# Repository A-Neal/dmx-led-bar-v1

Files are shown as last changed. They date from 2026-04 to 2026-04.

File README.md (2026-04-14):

# FPGA DMX Decoder and PWM Driver Written in Verilog

This project directory is uploaded as-is, and doesn't contain a lot of polish.

I used Apio to build the Verilog into a configuration for the FPGA, and developed
on a Lattice iCE40UP5k. You can use the underlying toolchain if you'd prefer, but
I recommend Apio if you aren't looking to get into the weeds and just want to
modify little bits of the Verilog or build it for a different FPGA.

If you are building exactly according to what's in this repo, you don't need to
have Apio or build the configuration. **hardware.bin** is the file that is already
built and padded to fit into the 2Mbit flash on the PCB.

To flash, I used a generic CH341A USB SPI flasher with `flashrom` to flash the
hardware.bin file.

`$ flashrom -p ch341a_spi -w hardware.bin`

This repo includes the KiCAD project for the PCB, as well as just the gerber files
for have the PCB produced if you don't want to do any mods.

The BOM file is a list of everything that goes on the PCB and a link to the part
on Mouser. It's inside the KiCAD project directory.

The LED strips I used get a little too hot for the channels I used when everything
is turned up, so I'm not going to recommend them. But I will link them anyway
because they're excellent for other uses or if you're building a beefier fixture
than these plans are for.

LED Strip I Used: https://a.co/d/0fOELpNe

Less Powerful Equivalent LED Strip: https://a.co/d/0jd0L9jr

Aluminum Diffuser Channels: https://a.co/d/0e7rKbcg

24V Power Supply: https://a.co/d/09dPfuRe

Use any 12-24V LED strip and power supply that you want so long as the strip fits
in the channels, and the power supply can push enough power comfortably.

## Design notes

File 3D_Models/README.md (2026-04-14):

# 3D Files

The 3mf files are ready for loading into your favorite slicer for 3D printing, and the FreeCAD project files are available for modifying directly. Most things in the project files are parameterized.

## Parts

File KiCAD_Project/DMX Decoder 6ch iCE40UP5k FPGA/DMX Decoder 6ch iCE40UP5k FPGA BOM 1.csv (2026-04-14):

Reference | Qty | Value | Notes | Footprint | Manufacturer | MFR Part # | Mouser Part #
C1,C12,C13,C14 | 4 | 10μF |  | Capacitor_SMD:C_0603_1608Metric | Samsung Electro-Mechanics | CL10A106KP8NQSC | 187-CL10A106KP8NQSC
C2,C3,C4,C5,C6,C7,C8,C9,C10,C11,C15,C16 | 12 | 100nF |  | Capacitor_SMD:C_0603_1608Metric | TAIYO YUDEN | UMK107BJ104KA-T | 963-UMK107BJ104KA-T
D1 | 1 | CDONE LED |  | LED_SMD:LED_0805_2012Metric | ROHM Semiconductor | SMLMN2BCTT86C | 755-SMLMN2BCTT86C
D2 | 1 | 10V Zener |  | Diode_SMD:D_SOD-123 | Vishay Semiconductor | BZT52C10-E3-18 | 78-BZT52C10-E3-18
J3 | 1 | IN - MALE |  | Connector_Audio:Jack_XLR_Neutrik_NC5MAV_Vertical | Neutrik/REAN | RRX5M-B-023-0 | 568-RRX5M-B-023-0
J4 | 1 | OUT - FEMALE |  | Connector_Audio:Jack_XLR_Neutrik_NC5FAV_Vertical | Neutrik/REAN | RRX5F-B-022-0 | 568-RRX5F-B-022-0
Q1,Q2,Q3,Q4,Q5,Q6 | 6 | T2N7002AK N-MOSFET |  | Package_TO_SOT_SMD:SOT-23 | Toshiba | T2N7002AK,LM | 757-T2N7002AKLM
Q7,Q8,Q9,Q10,Q11,Q12 | 6 | DMG4496SSS N-MOSFET |  | Package_SO:SOIC-8_3.9x4.9mm_P1.27mm | Diodes Incorporated | DMG4496SSS13 | 621-DMG4496SSS13
Q14 | 1 | SI4435 P-MOSFET |  | Package_TO_SOT_SMD:SOT-23 | Vishay / Siliconix | SI4435FDY-T1-GE3 | 78-SI4435FDY-T1-GE3
R1,R2,R3,R4,R5,R6 | 6 | 5.1k |  | Resistor_SMD:R_0603_1608Metric | Panasonic | ERJ-U03F5101V | 667-ERJ-U03F5101V
R7,R8,R9,R10,R11,R12 | 6 | 3.3k |  | Resistor_SMD:R_0603_1608Metric | Panasonic | ERJ-U03F3301V | 667-ERJ-U03F3301V
R13 | 1 | 100Ω |  | Resistor_SMD:R_0603_1608Metric | Panasonic | ERJ-U03F1000V | 667-ERJ-U03F1000V
R14,R16,R17,R18,R19,R20 | 6 | 10k |  | Resistor_SMD:R_0603_1608Metric | Panasonic | ERJ-U03F1002V | 667-ERJ-U03F1002V
R15 | 1 | 2.2k |  | Resistor_SMD:R_0603_1608Metric | Panasonic | ERJ-U03F2201V | 667-ERJ-U03F2201V
U1 | 1 | ICE40UP5K-SG48ITR |  | Package_DFN_QFN:QFN-48-1EP_7x7mm_P0.5mm_EP5.6x5.6mm | Lattice | ICE40UP5K-SG48I | 842-ICE40UP5K-SG48I
U2 | 1 | THVD1420D |  | Package_SO:SOIC-8_3.9x4.9mm_P1.27mm | Texas Instruments | THVD1420DR | 595-THVD1420DR
U3 | 1 | AT25xxx-MA |  | Package_DFN_QFN:DFN-8-1EP_3x2mm_P0.5mm_EP1.75x1.45mm | Renesas Electronics | AT25EU0021AMAHNT | 724-AT25EU0021AMAHNT
U4 | 1 | 1.2V REG |  | Package_SON:WSON-6-1EP_2x2mm_P0.65mm_EP1x1.6mm | Texas Instruments | TPS70912DRVT | 595-TPS70912DRVT
U5 | 1 | 2.5V REG |  | Package_SON:WSON-6-1EP_2x2mm_P0.65mm_EP1x1.6mm | Texas Instruments | TPS70925DRVR | 595-TPS70925DRVR
U6 | 1 | 3.3V REG |  | Package_SON:WSON-6-1EP_2x2mm_P0.65mm_EP1x1.6mm | Texas Instruments | TPS70933DRVR | 595-TPS70933DRVR
Y1 | 1 | ASCO 12MHz |  | Oscillator:Oscillator_SMD_Abracon_ASCO-4Pin_1.6x1.2mm | Microchip | DSC1001DI5-012.0000 | 998-DSC1001DI5-012.0000
J1 | 1 | LED STRIP CATHODES 1-6 | Generic Screw Terminals | TerminalBlock:TerminalBlock_MaiXu_MX126-5.0-06P_1x06_P5.00mm | GCT | TAH05-02-1-L-G | 640-TAH05-02-1-L-G
J2 | 1 | 24V Input Pos-C | Generic horizontal 5mm barrel jack | Custom:BarrelJack_Horizontal_CUI_PJ-057A | Same Sky (Formerly CUI) | PJ-057A | 490-PJ-057A
J5 | 1 | FLASH SPI | Generic 0.100” pitch pin headers | Connector_PinHeader_2.54mm:PinHeader_1x06_P2.54mm_Vertical | Amphenol | 77311-122-06LF | 649-77311-122-06LF
J6 | 1 | 24V COM | Generic Screw Terminals | TerminalBlock:TerminalBlock_MaiXu_MX126-5.0-02P_1x02_P5.00mm | GCT | TAH05-02-1-L-G | 640-TAH05-02-1-L-G
JP1 | 1 | RST JMPR | Generic 0.050” pitch pin headers | Connector_PinHeader_1.27mm:PinHeader_1x02_P1.27mm_Vertical | Samtec | TMS-102-21-G-S | 200-TMS-102-21-G-S

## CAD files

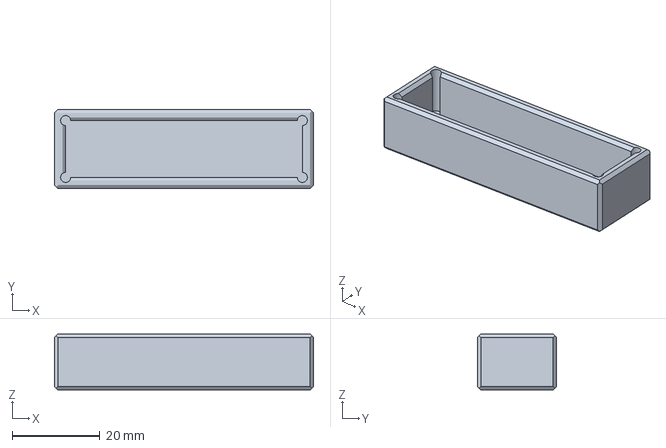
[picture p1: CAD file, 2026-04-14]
3D_Models/LED Bar End Cap 2.3mf
59.1 x 18.0 x 12.7 mm

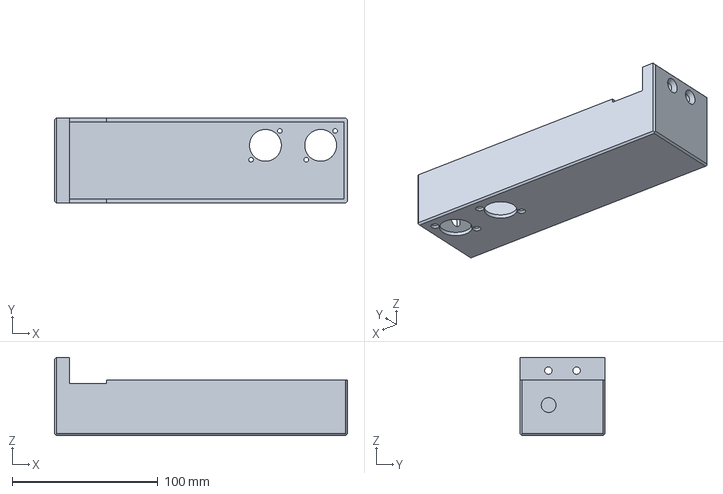
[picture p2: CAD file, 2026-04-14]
3D_Models/LED Bar PCB Box.3mf
201.2 x 58.2 x 53.6 mm

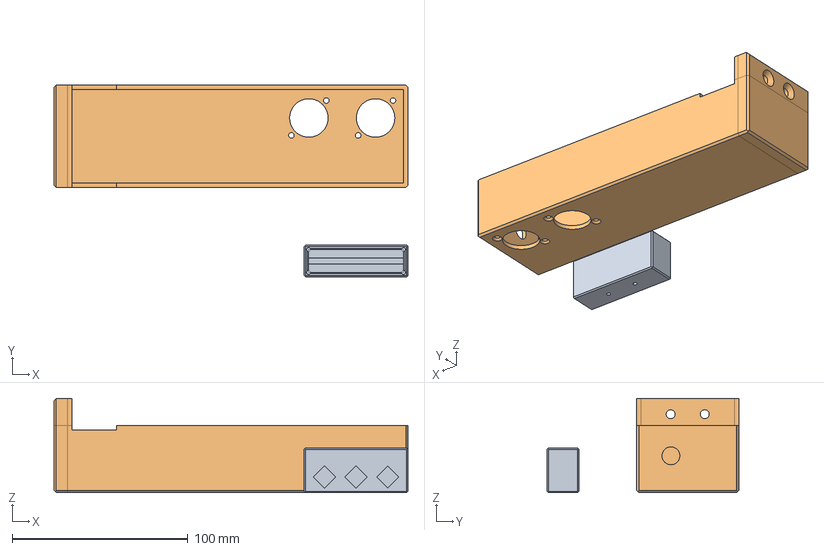
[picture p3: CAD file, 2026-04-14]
3D_Models/LED Bar DMX End Cap.FCStd
201.2 x 109.0 x 53.6 mm

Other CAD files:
3D_Models/LED Bar End Cap.FCStd
3D_Models/LED Bar DMX End Cap.3mf

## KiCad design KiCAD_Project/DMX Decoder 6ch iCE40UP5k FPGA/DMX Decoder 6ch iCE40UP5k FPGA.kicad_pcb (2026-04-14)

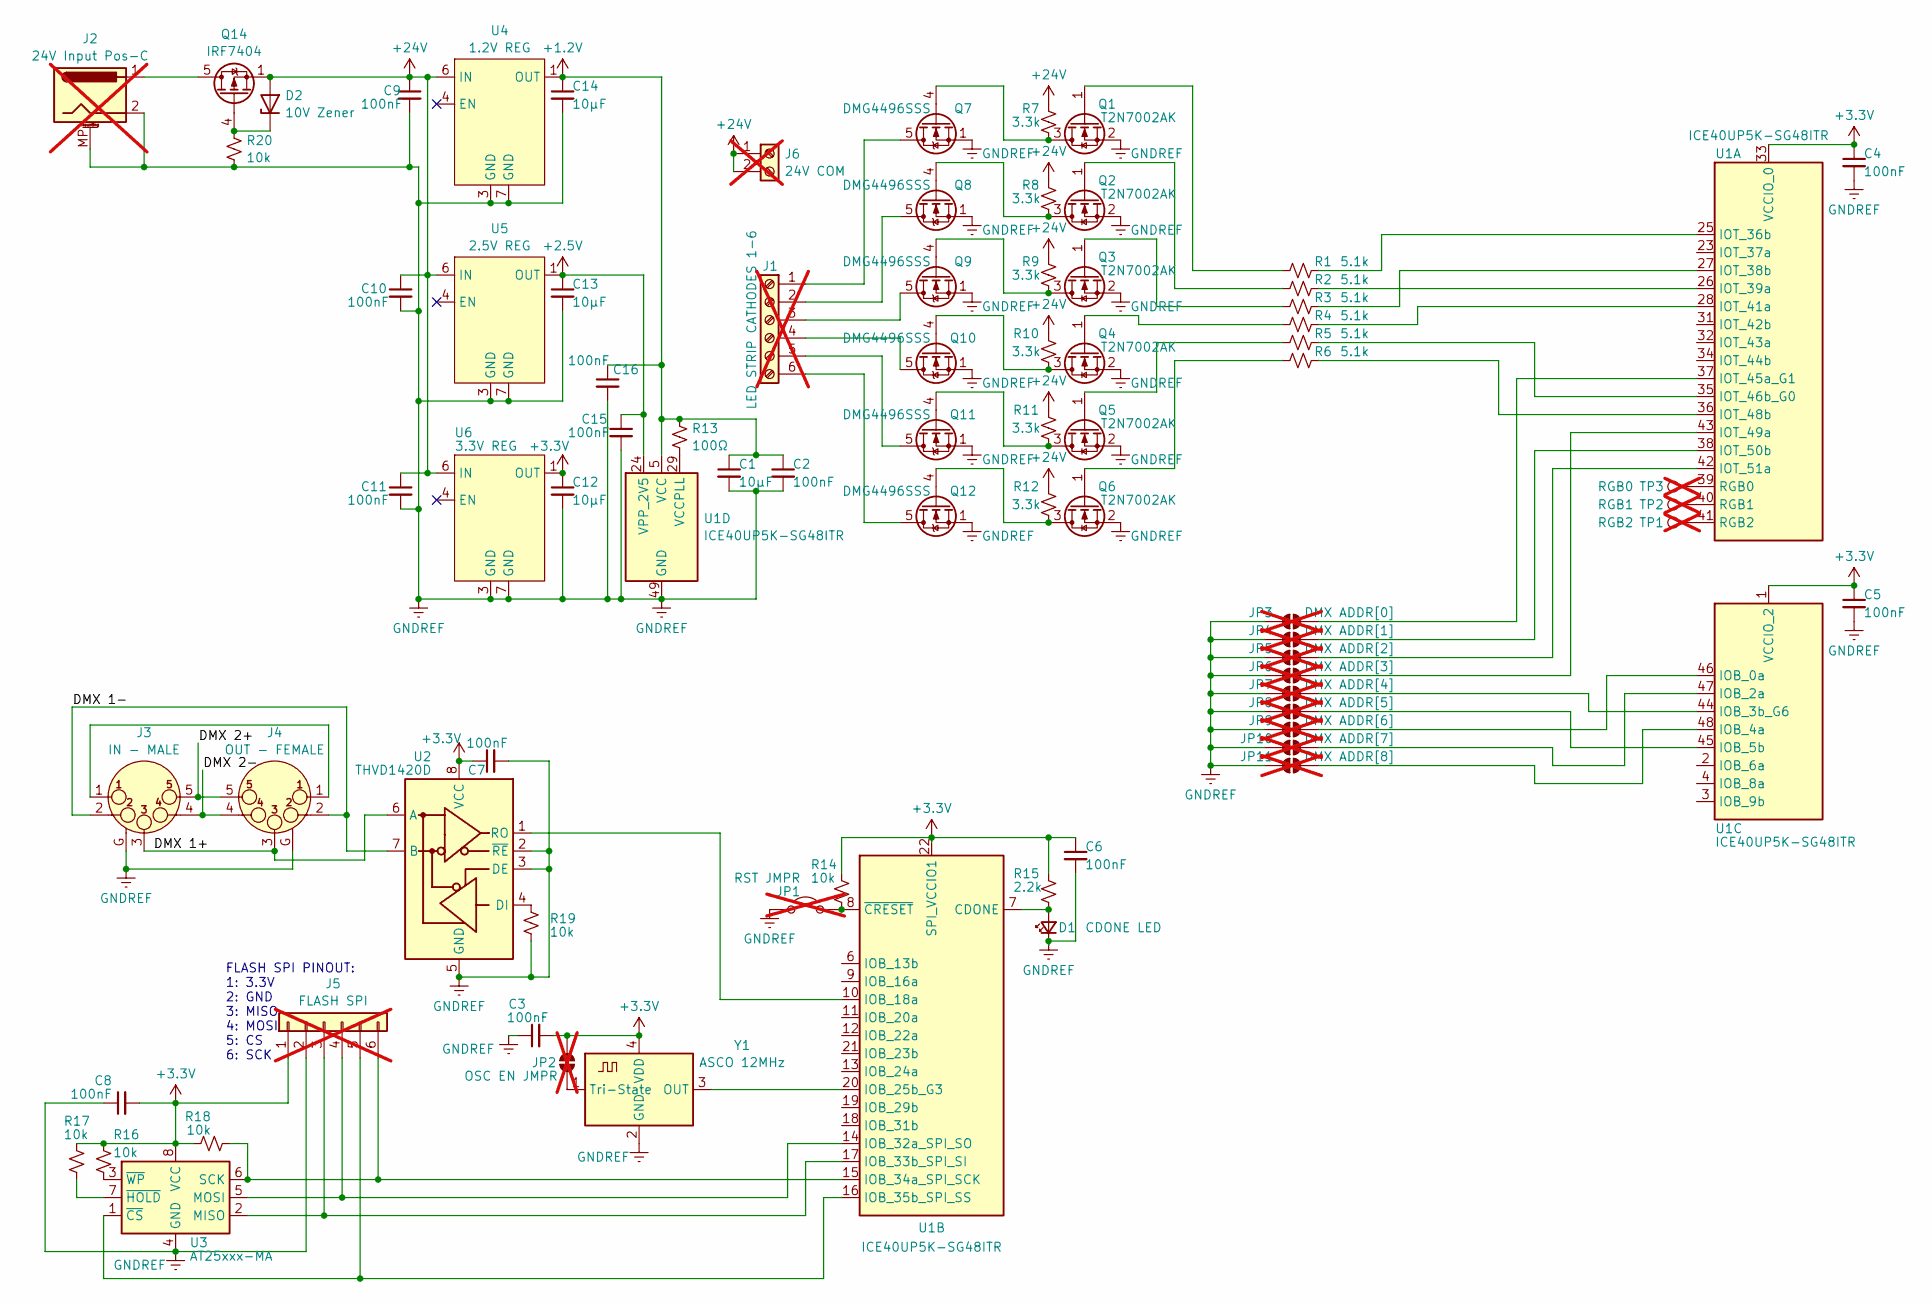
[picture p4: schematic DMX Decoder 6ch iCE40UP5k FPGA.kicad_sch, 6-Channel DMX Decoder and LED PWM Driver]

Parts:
C1, C12, C13, C14: 10μF; C_0603_1608Metric
C2, C3, C4, C5, C6, C7, C8, C9, C10, C11, C15, C16: 100nF; C_0603_1608Metric
D1: CDONE LED; LED_0805_2012Metric
D2: 10V Zener; D_SOD-123
J1: LED STRIP CATHODES 1-6; TerminalBlock_MaiXu_MX126-5.0-06P_1x06_P5.00mm; not fitted
J2: 24V Input Pos-C; BarrelJack_Horizontal_CUI_PJ-057A; not fitted
J3: IN - MALE; Jack_XLR_Neutrik_NC5MAV_Vertical
J4: OUT - FEMALE; Jack_XLR_Neutrik_NC5FAV_Vertical
J5: FLASH SPI; PinHeader_1x06_P2.54mm_Vertical; not fitted
J6: 24V COM; TerminalBlock_MaiXu_MX126-5.0-02P_1x02_P5.00mm; not fitted
JP1: RST JMPR; PinHeader_1x02_P1.27mm_Vertical; not fitted
JP2: OSC EN JMPR; SolderJumper-2_P1.3mm_Open_TrianglePad1.0x1.5mm; not fitted
JP3: DMX ADDR[0]; SolderJumper-2_P1.3mm_Open_TrianglePad1.0x1.5mm; not fitted
JP4: DMX ADDR[1]; SolderJumper-2_P1.3mm_Open_TrianglePad1.0x1.5mm; not fitted
JP5: DMX ADDR[2]; SolderJumper-2_P1.3mm_Open_TrianglePad1.0x1.5mm; not fitted
JP6: DMX ADDR[3]; SolderJumper-2_P1.3mm_Open_TrianglePad1.0x1.5mm; not fitted
JP7: DMX ADDR[4]; SolderJumper-2_P1.3mm_Open_TrianglePad1.0x1.5mm; not fitted
JP8: DMX ADDR[5]; SolderJumper-2_P1.3mm_Open_TrianglePad1.0x1.5mm; not fitted
JP9: DMX ADDR[6]; SolderJumper-2_P1.3mm_Open_TrianglePad1.0x1.5mm; not fitted
JP10: DMX ADDR[7]; SolderJumper-2_P1.3mm_Open_TrianglePad1.0x1.5mm; not fitted
JP11: DMX ADDR[8]; SolderJumper-2_P1.3mm_Open_TrianglePad1.0x1.5mm; not fitted
Q1, Q2, Q3, Q4, Q5, Q6: T2N7002AK; SOT-23
Q7, Q8, Q9, Q10, Q11, Q12: DMG4496SSS; SOIC-8_3.9x4.9mm_P1.27mm
Q14: IRF7404; SOIC-8_3.9x4.9mm_P1.27mm
R1, R2, R3, R4, R5, R6: 5.1k; R_0603_1608Metric
R7, R8, R9, R10, R11, R12: 3.3k; R_0603_1608Metric
R13: 100Ω; R_0603_1608Metric
R14, R16, R17, R18, R19, R20: 10k; R_0603_1608Metric
R15: 2.2k; R_0603_1608Metric
TP1: RGB2; Pin_D0.7mm_L6.5mm_W1.8mm_FlatFork; not fitted
TP2: RGB1; Pin_D0.7mm_L6.5mm_W1.8mm_FlatFork; not fitted
TP3: RGB0; Pin_D0.7mm_L6.5mm_W1.8mm_FlatFork; not fitted
U1: ICE40UP5K-SG48ITR; QFN-48-1EP_7x7mm_P0.5mm_EP5.6x5.6mm
U2: THVD1420D; SOIC-8_3.9x4.9mm_P1.27mm
U3: AT25xxx-MA; DFN-8-1EP_3x2mm_P0.5mm_EP1.75x1.45mm
U4: 1.2V REG; WSON-6-1EP_2x2mm_P0.65mm_EP1x1.6mm
U5: 2.5V REG; WSON-6-1EP_2x2mm_P0.65mm_EP1x1.6mm
U6: 3.3V REG; WSON-6-1EP_2x2mm_P0.65mm_EP1x1.6mm
Y1: ASCO 12MHz; Oscillator_SMD_Abracon_ASCO-4Pin_1.6x1.2mm

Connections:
+1.2V: C1.1, C2.1, C14.1, C16.1, R13.2, U1.5 (VCC), U1.30 (VCC), U4.1 (OUT)
+2.5V: C13.1, C15.1, U1.24 (VPP_2V5), U5.1 (OUT)
+3.3V: C3.2, C4.1, C5.1, C6.1, C7.1, C8.2, C12.1, J5.1, JP2.2 (B), R14.2, R15.2, R16.2, R17.2, R18.2, U1.1 (VCCIO_2), U1.22 (SPI_VCCIO1), U1.33 (VCCIO_0), U2.8 (VCC), U3.8 (VCC), U6.1 (OUT), Y1.4 (VDD)
+24V: C9.1, C10.1, C11.1, D2.2 (A), J6.1, J6.2, Q14.1 (S), Q14.2 (S), Q14.3 (S), R7.2, R8.2, R9.2, R10.2, R11.2, R12.2, U4.6 (IN), U5.6 (IN), U6.6 (IN)
/DMX 1+: J3.3, J4.3, U2.6 (A)
/DMX 1-: J3.2, J4.2, U2.7 (B)
/DMX 2+: J3.5, J4.5
/DMX 2-: J3.4 (P3), J4.4 (P3)
GNDREF: C1.2, C2.2, C3.1, C4.2, C5.2, C6.2, C7.2, C8.1, C9.2, C10.2, C11.2, C12.2, C13.2, C14.2, C15.2, C16.2, D1.1 (K), J2.2, J2.MP (MountPin_MP), J3.G, J4.G, J5.2, JP1.1 (A), JP3.1 (A), JP4.1 (A), JP5.1 (A), JP6.1 (A), JP7.1 (A), JP8.1 (A), JP9.1 (A), JP10.1 (A), JP11.1 (A), Q1.2 (S), Q2.2 (S), Q3.2 (S), Q4.2 (S), Q5.2 (S), Q6.2 (S), Q7.1 (S), Q7.2 (S), Q7.3 (S), Q8.1 (S), Q8.2 (S), Q8.3 (S), Q9.1 (S), Q9.2 (S), Q9.3 (S), Q10.1 (S), Q10.2 (S), Q10.3 (S), Q11.1 (S), Q11.2 (S), Q11.3 (S), Q12.1 (S), Q12.2 (S), Q12.3 (S), R19.1, R20.1, U1.49 (GND), U2.2 (~RE), U2.3 (DE), U2.5 (GND), U3.4 (GND), U3.9 (GND), U4.3 (GND), U4.7 (GND), U5.3 (GND), U5.7 (GND), U6.3 (GND), U6.7 (GND), Y1.2 (GND)
unnamed: D1.2 (A), R15.1, U1.7 (CDONE)
unnamed: D2.1 (K), Q14.4 (G), R20.2
unnamed: J1.1, Q7.5 (D), Q7.6 (D), Q7.7 (D), Q7.8 (D)
unnamed: J1.2, Q8.5 (D), Q8.6 (D), Q8.7 (D), Q8.8 (D)
unnamed: J1.3, Q9.5 (D), Q9.6 (D), Q9.7 (D), Q9.8 (D)
unnamed: J1.4, Q10.5 (D), Q10.6 (D), Q10.7 (D), Q10.8 (D)
unnamed: J1.5, Q11.5 (D), Q11.6 (D), Q11.7 (D), Q11.8 (D)
unnamed: J1.6, Q12.5 (D), Q12.6 (D), Q12.7 (D), Q12.8 (D)
unnamed: J2.1, Q14.5 (D), Q14.6 (D), Q14.7 (D), Q14.8 (D)
unnamed: J3.1, J4.1
unnamed: J5.3, U1.17 (IOB_33b_SPI_SI), U3.2 (MISO)
unnamed: J5.4, U1.14 (IOB_32a_SPI_SO), U3.5 (MOSI)
unnamed: J5.5, U1.16 (IOB_35b_SPI_SS), U3.1 (~CS)
unnamed: J5.6, R18.1, U1.15 (IOB_34a_SPI_SCK), U3.6 (SCK)
unnamed: JP1.2 (B), R14.1, U1.8 (~CRESET)
unnamed: JP2.1 (A), Y1.1 (Tri-State)
unnamed: JP3.2 (B), U1.37 (IOT_45a_G1)
unnamed: JP4.2 (B), U1.38 (IOT_50b)
unnamed: JP5.2 (B), U1.42 (IOT_51a)
unnamed: JP6.2 (B), U1.43 (IOT_49a)
unnamed: JP7.2 (B), U1.44 (IOB_3b_G6)
unnamed: JP8.2 (B), U1.45 (IOB_5b)
unnamed: JP9.2 (B), U1.46 (IOB_0a)
unnamed: JP10.2 (B), U1.47 (IOB_2a)
unnamed: JP11.2 (B), U1.48 (IOB_4a)
unnamed: Q1.3 (D), Q7.4 (G), R7.1
unnamed: Q1.1 (G), R1.1
unnamed: Q2.3 (D), Q8.4 (G), R8.1
unnamed: Q2.1 (G), R2.1
unnamed: Q3.3 (D), Q9.4 (G), R9.1
unnamed: Q3.1 (G), R3.1
unnamed: Q4.1 (G), R4.1
unnamed: Q5.1 (G), R5.1
unnamed: Q6.1 (G), R6.1
unnamed: Q4.3 (D), Q10.4 (G), R10.1
unnamed: Q5.3 (D), Q11.4 (G), R11.1
unnamed: Q6.3 (D), Q12.4 (G), R12.1
unnamed: R1.2, U1.25 (IOT_36b)
unnamed: R3.2, U1.27 (IOT_38b)
unnamed: R2.2, U1.26 (IOT_39a)
unnamed: R4.2, U1.28 (IOT_41a)
unnamed: R5.2, U1.35 (IOT_46b_G0)
unnamed: R6.2, U1.36 (IOT_48b)
unnamed: TP3.1 (1_1), U1.39 (RGB0)
unnamed: TP2.1 (1_1), U1.40 (RGB1)
unnamed: TP1.1 (1_1), U1.41 (RGB2)
unnamed: U1.10 (IOB_18a), U2.1 (RO)
unnamed: U1.20 (IOB_25b_G3), Y1.3 (OUT)
unnamed: R13.1, U1.29 (VCCPLL)
unnamed: R19.2, U2.4 (DI)
unnamed: R17.1, U3.7 (~HOLD)
unnamed: R16.1, U3.3 (~WP)

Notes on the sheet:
FLASH SPI PINOUT: 1: 3.3V 2: GND 3: MISO 4: MOSI 5: CS 6: SCK

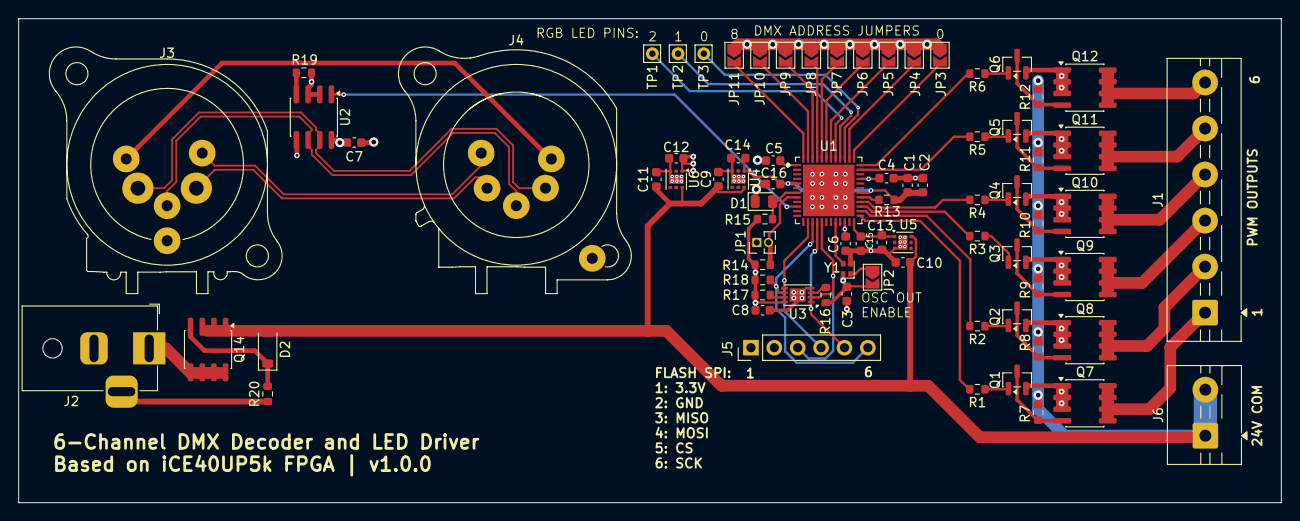
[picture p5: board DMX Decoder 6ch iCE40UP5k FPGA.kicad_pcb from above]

Board: 4 copper layers, 137.2 x 52.6 mm, 78 parts (0 on the bottom side), 61 nets.

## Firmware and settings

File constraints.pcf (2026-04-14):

# iCE Sugar dev board pin constraints
#set_io		CLK_12MHz	35
#set_io		DMX_INPUT	10
#set_io		DMX_ADDR[0]	46
#set_io		DMX_ADDR[1]	44
#set_io		DMX_ADDR[2]	42
#set_io		DMX_ADDR[3]	37
#set_io		DMX_ADDR[4]	48
#set_io		DMX_ADDR[5]	34
#set_io		DMX_ADDR[6]	31
#set_io		DMX_ADDR[7]	27
#set_io		DMX_ADDR[8]	25
#set_io		PWM_OUT[0]	45
#set_io		PWM_OUT[1]	43
#set_io		PWM_OUT[2]	38
#set_io		PWM_OUT[3]	36
#set_io		PWM_OUT[4]	47
#set_io		PWM_OUT[5]	32

# Custom PCB pin constraints
set_io		CLK_12MHz	20
set_io		DMX_INPUT	10
set_io		-pullup yes	DMX_ADDR[0]	37
set_io		-pullup yes	DMX_ADDR[1]	38
set_io		-pullup yes	DMX_ADDR[2]	42
set_io		-pullup yes	DMX_ADDR[3]	43
set_io		-pullup yes	DMX_ADDR[4]	44
set_io		-pullup yes	DMX_ADDR[5]	45
set_io		-pullup yes	DMX_ADDR[6]	46
set_io		-pullup yes	DMX_ADDR[7]	47
set_io		-pullup yes	DMX_ADDR[8]	48
set_io		PWM_OUT[0]	25
set_io		PWM_OUT[1]	26
set_io		PWM_OUT[2]	27
set_io		PWM_OUT[3]	28
set_io		PWM_OUT[4]	35
set_io		PWM_OUT[5]	36

set_io		DEBUG_OUT	13

set_frequency	CLK_12MHz	12
